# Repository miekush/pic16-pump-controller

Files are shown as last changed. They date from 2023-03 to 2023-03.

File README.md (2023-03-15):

# pic16-pump-controller
PIC16 based Pump Controller for Smart Plant Watering and Coffee Makers

# PCB

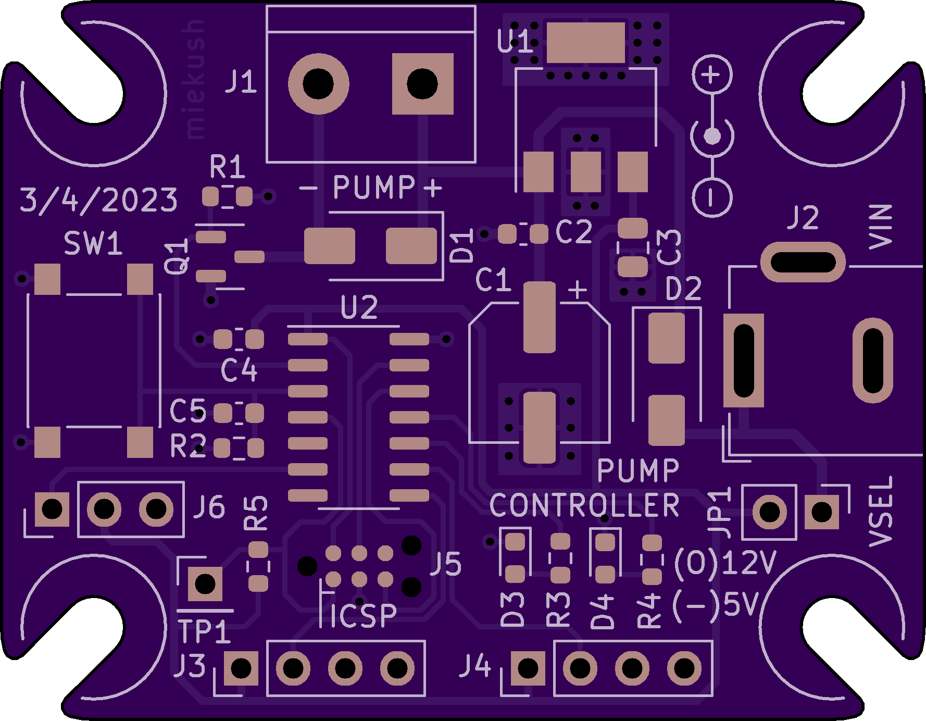
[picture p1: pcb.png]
Board Image


# License

MKE supports the open source hardware community by sharing hardware design files freely on GitHub!

Please support MKE by purchasing products on [Tindie](https://www.tindie.com/stores/mkengineering/)!

Designed by Mike Kushnerik (miekush)

Licensed under [Creative Commons Attribution-ShareAlike CC BY-SA 4.0](http://creativecommons.org/licenses/by-sa/4.0/)

All text above must be included in any redistribution!

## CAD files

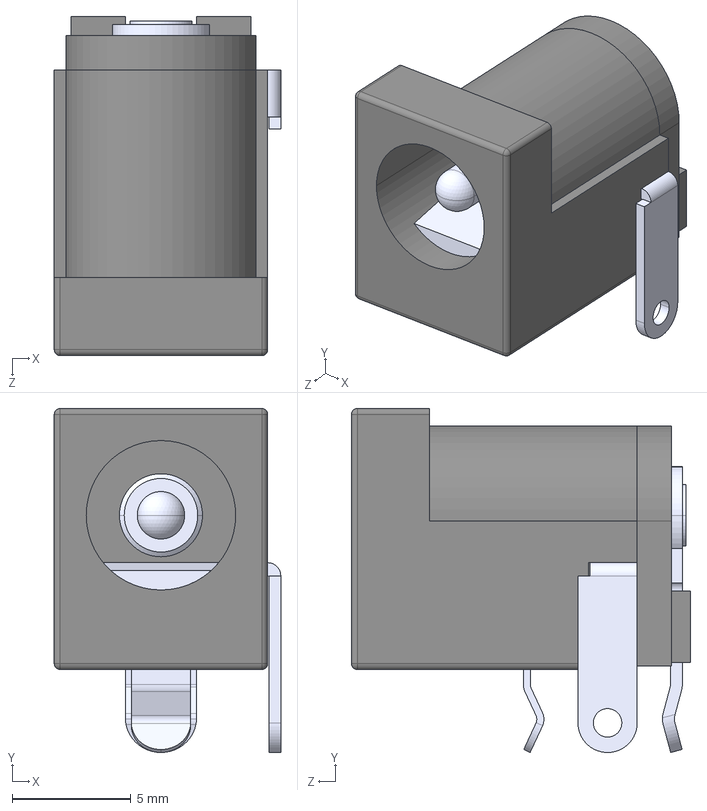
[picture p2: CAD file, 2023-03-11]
DCJ200-10-A-K1-K--3DModel-STEP-56544.STEP
9.55 x 14.5 x 14.3 mm

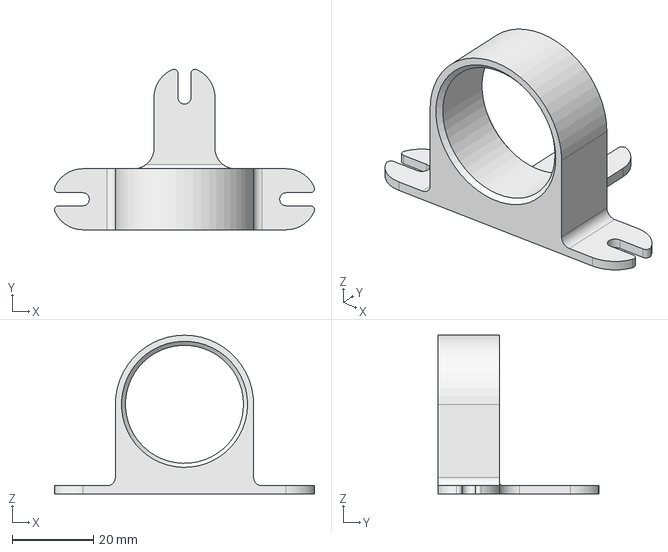
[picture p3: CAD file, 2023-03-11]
pump-suction-mount/pump_suction_mount.FCStd
63.9 x 39.5 x 39.0 mm

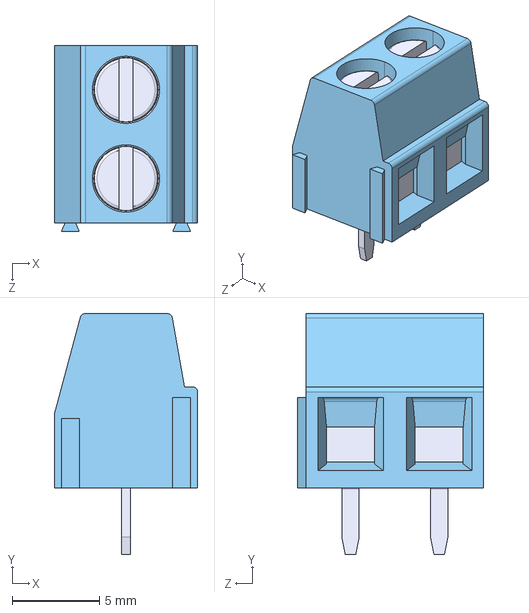
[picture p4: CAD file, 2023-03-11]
CUI_DEVICES_TB006-508-02BE.step
8.20 x 13.8 x 10.7 mm

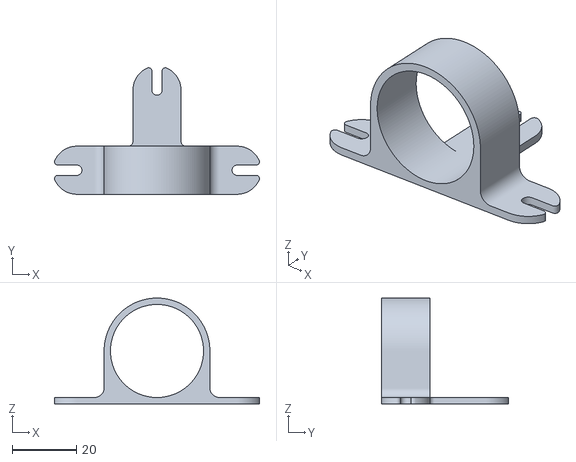
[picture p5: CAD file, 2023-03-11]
pump-suction-mount/pump_suction_mount-Body.stl
63.9 x 39.5 x 33.0

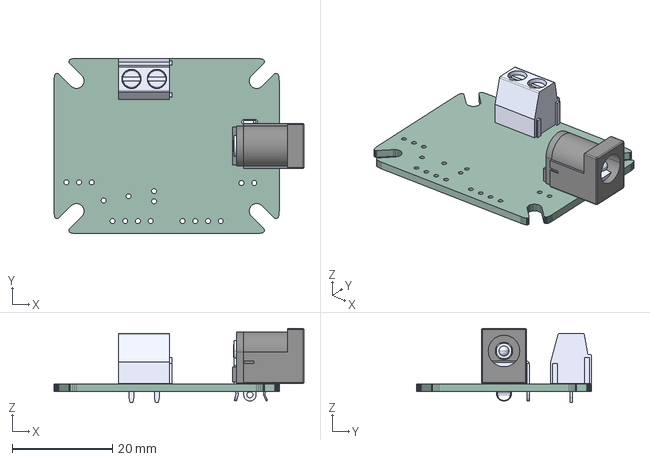
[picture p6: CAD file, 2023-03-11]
pic16-pump-controller.step
49.9 x 35.0 x 14.8 mm
PCB

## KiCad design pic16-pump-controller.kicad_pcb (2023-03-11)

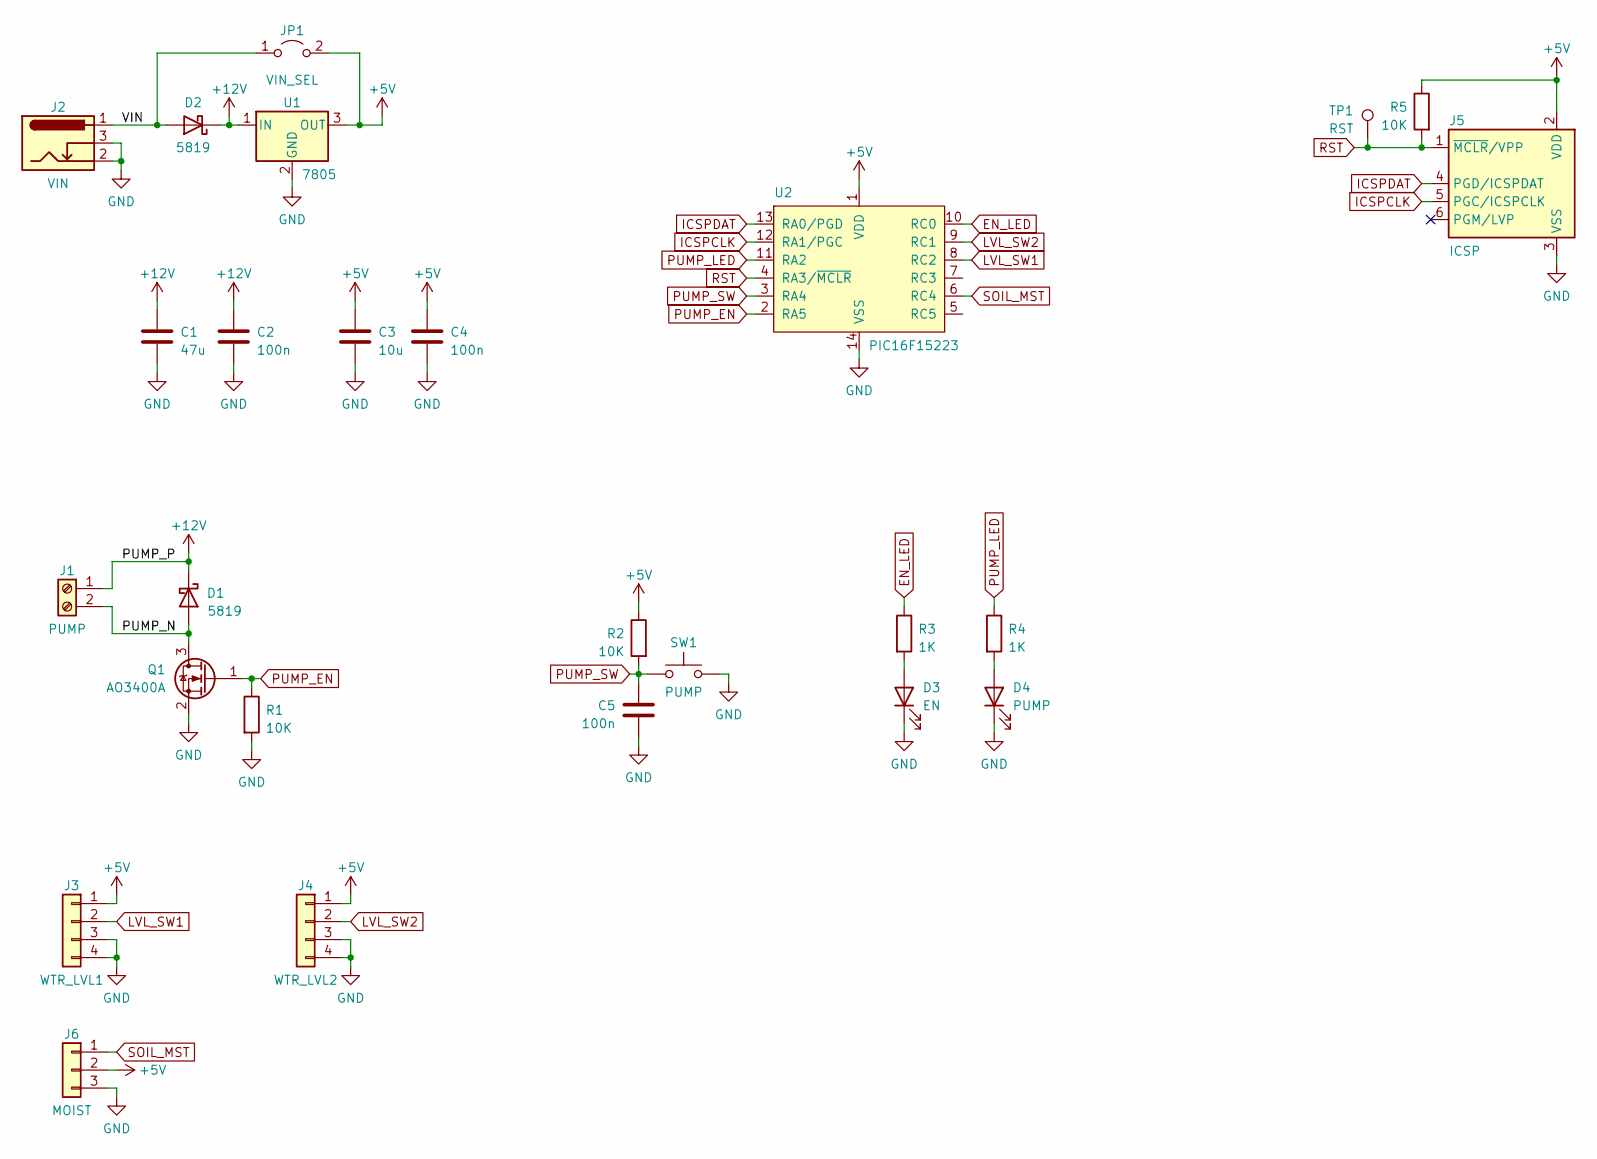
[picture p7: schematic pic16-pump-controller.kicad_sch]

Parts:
C1: 47u; CP_Elec_6.3x5.8
C2, C4, C5: 100n; C_0603_1608Metric
C3: 10u; C_0805_2012Metric
D1, D2: 5819; D_SMA
D3: EN; LED_0603_1608Metric
D4: PUMP; LED_0603_1608Metric
J1: PUMP; TerminalBlock_bornier-2_P5.08mm
J2: VIN; BarrelJack_GCT_DCJ200-10-A_Horizontal
J3: WTR_LVL1; PinHeader_1x04_P2.54mm_Vertical
J4: WTR_LVL2; PinHeader_1x04_P2.54mm_Vertical
J5: ICSP; Tag-Connect_TC2030-IDC-NL_2x03_P1.27mm_Vertical
J6: MOIST; PinHeader_1x03_P2.54mm_Vertical
JP1: VIN_SEL; PinHeader_1x02_P2.54mm_Vertical
Q1: AO3400A; SOT-23
R1, R2, R5: 10K; R_0603_1608Metric
R3, R4: 1K; R_0603_1608Metric
SW1: PUMP; SW_Push_1P1T_NO_6x6mm_H9.5mm
TP1: RST; PinHeader_1x01_P2.54mm_Vertical
U1: 7805; SOT-223-3_TabPin2
U2: PIC16F15223; SOIC-14_3.9x8.7mm_P1.27mm

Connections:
+5V: C3.1, C4.1, J3.1, J4.1, J5.2 (VDD), J6.2, JP1.2 (B), R2.1, R5.1, U1.3 (OUT), U2.1 (VDD)
+12V: C1.1, C2.1, D1.1 (K), D2.1 (K), J1.1, U1.1 (IN)
/PUMP_N: D1.2 (A), J1.2, Q1.3 (D)
/VIN: D2.2 (A), J2.1, JP1.1 (A)
EN_LED: R3.1, U2.10 (RC0)
GND: C1.2, C2.2, C3.2, C4.2, C5.2, D3.1 (K), D4.1 (K), J2.2, J2.3, J3.3, J3.4, J4.3, J4.4, J5.3 (VSS), J6.3, Q1.2 (S), R1.2, SW1.2, U1.2 (GND), U2.14 (VSS)
ICSPCLK: J5.5 (PGC/ICSPCLK), U2.12 (RA1/PGC)
ICSPDAT: J5.4 (PGD/ICSPDAT), U2.13 (RA0/PGD)
LVL_SW1: J3.2, U2.8 (RC2)
LVL_SW2: J4.2, U2.9 (RC1)
unnamed: D3.2 (A), R3.2
unnamed: D4.2 (A), R4.2
PUMP_EN: Q1.1 (G), R1.1, U2.2 (RA5)
PUMP_LED: R4.1, U2.11 (RA2)
PUMP_SW: C5.1, R2.2, SW1.1, U2.3 (RA4)
RST: J5.1 (~MCLR/VPP), R5.2, TP1.1, U2.4 (RA3/~MCLR)
SOIL_MST: J6.1, U2.6 (RC4)

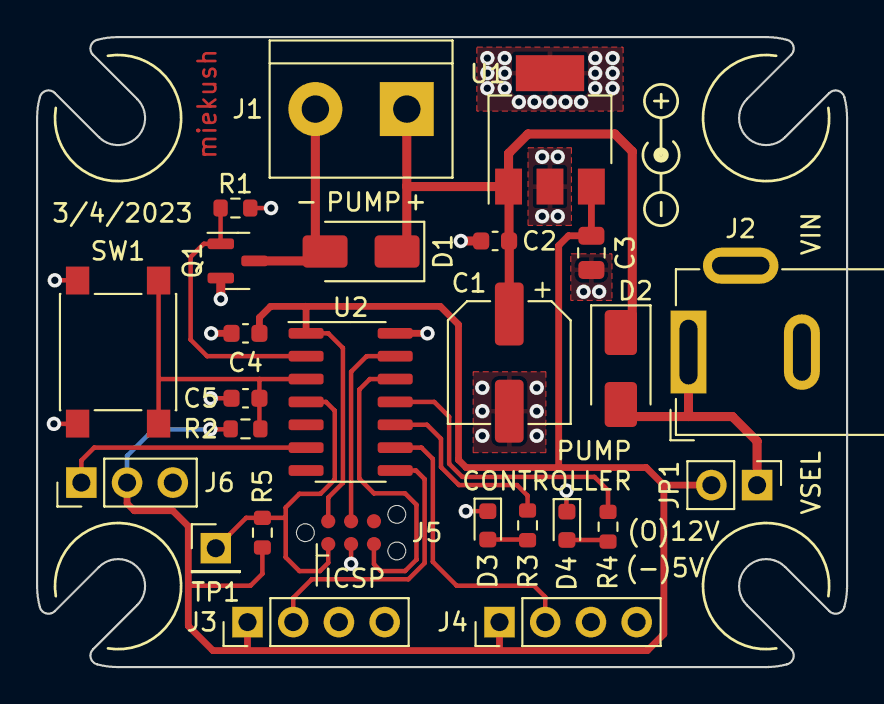
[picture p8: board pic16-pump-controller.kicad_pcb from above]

Board: 2 copper layers, 45.0 x 35.0 mm, 26 parts (0 on the bottom side), 17 nets.

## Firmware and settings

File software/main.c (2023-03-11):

#include "mcc_generated_files/mcc.h"

uint8_t pumpState = false;
uint16_t pumpCounter = 0;
const uint16_t tankFillTime = 5000;

uint16_t ledCounter = 0;
const uint16_t ledPeriod = 500;

//function prototypes
void levelSwISR(void);
void timer0ISR(void);

void main(void)
{
    // initialize the device
    SYSTEM_Initialize();

    // Enable the Global Interrupts
    INTERRUPT_GlobalInterruptEnable();

    // Enable the Peripheral Interrupts
    INTERRUPT_PeripheralInterruptEnable();
    
    //attach interrupt handlers
    TMR0_SetInterruptHandler(timer0ISR);
    IOCCF2_SetInterruptHandler(levelSwISR);

    TMR0_StartTimer();
    
    while (1)
    {
        //pump on
        if((pumpState || !PUMP_SW_GetValue()) && !LVL_SW2_GetValue())
        {
            PUMP_EN_SetHigh();
            PUMP_LED_SetHigh();
            
            if(ledCounter > ledPeriod)
            {
                STAT_LED_Toggle();
                ledCounter = 0;
            }
        }
        //pump off
        else
        {
            PUMP_EN_SetLow();
            PUMP_LED_SetLow();
            
            if(!LVL_SW2_GetValue())
            {
                STAT_LED_SetHigh();
            }
            else
            {
                STAT_LED_SetLow();
            }
        }
    }
}

void levelSwISR(void)
{
    pumpState = true;
    pumpCounter = 0;
    ledCounter = 0;
}

void timer0ISR(void)
{
    pumpCounter++;
    ledCounter++;
    
    if(pumpState && (pumpCounter > tankFillTime))
    {
        pumpState = false;
    }
}

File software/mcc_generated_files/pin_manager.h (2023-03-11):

/**
  @Generated Pin Manager Header File

  @Company:
    Microchip Technology Inc.

  @File Name:
    pin_manager.h

  @Summary:
    This is the Pin Manager file generated using PIC10 / PIC12 / PIC16 / PIC18 MCUs

  @Description
    This header file provides APIs for driver for .
    Generation Information :
        Product Revision  :  PIC10 / PIC12 / PIC16 / PIC18 MCUs - 1.81.8
        Device            :  PIC16F15223
        Driver Version    :  2.11
    The generated drivers are tested against the following:
        Compiler          :  XC8 2.36 and above
        MPLAB 	          :  MPLAB X 6.00	
*/

/*
    (c) 2018 Microchip Technology Inc. and its subsidiaries. 
    
    Subject to your compliance with these terms, you may use Microchip software and any 
    derivatives exclusively with Microchip products. It is your responsibility to comply with third party 
    license terms applicable to your use of third party software (including open source software) that 
    may accompany Microchip software.
    
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
    IN NO EVENT WILL MICROCHIP BE LIABLE FOR ANY INDIRECT, SPECIAL, PUNITIVE, 
    INCIDENTAL OR CONSEQUENTIAL LOSS, DAMAGE, COST OR EXPENSE OF ANY KIND 
    WHATSOEVER RELATED TO THE SOFTWARE, HOWEVER CAUSED, EVEN IF MICROCHIP 
    HAS BEEN ADVISED OF THE POSSIBILITY OR THE DAMAGES ARE FORESEEABLE. TO 
    THE FULLEST EXTENT ALLOWED BY LAW, MICROCHIP'S TOTAL LIABILITY ON ALL 
    CLAIMS IN ANY WAY RELATED TO THIS SOFTWARE WILL NOT EXCEED THE AMOUNT 
    OF FEES, IF ANY, THAT YOU HAVE PAID DIRECTLY TO MICROCHIP FOR THIS 
    SOFTWARE.
*/

#ifndef PIN_MANAGER_H
#define PIN_MANAGER_H

/**
  Section: Included Files
*/

#include <xc.h>

#define INPUT   1
#define OUTPUT  0

#define HIGH    1
#define LOW     0

#define ANALOG      1
#define DIGITAL     0

#define PULL_UP_ENABLED      1
#define PULL_UP_DISABLED     0

// get/set PUMP_LED aliases
#define PUMP_LED_TRIS                 TRISAbits.TRISA2
#define PUMP_LED_LAT                  LATAbits.LATA2
#define PUMP_LED_PORT                 PORTAbits.RA2
#define PUMP_LED_WPU                  WPUAbits.WPUA2
#define PUMP_LED_OD                   ODCONAbits.ODCA2
#define PUMP_LED_ANS                  ANSELAbits.ANSA2
#define PUMP_LED_SetHigh()            do { LATAbits.LATA2 = 1; } while(0)
#define PUMP_LED_SetLow()             do { LATAbits.LATA2 = 0; } while(0)
#define PUMP_LED_Toggle()             do { LATAbits.LATA2 = ~LATAbits.LATA2; } while(0)
#define PUMP_LED_GetValue()           PORTAbits.RA2
#define PUMP_LED_SetDigitalInput()    do { TRISAbits.TRISA2 = 1; } while(0)
#define PUMP_LED_SetDigitalOutput()   do { TRISAbits.TRISA2 = 0; } while(0)
#define PUMP_LED_SetPullup()          do { WPUAbits.WPUA2 = 1; } while(0)
#define PUMP_LED_ResetPullup()        do { WPUAbits.WPUA2 = 0; } while(0)
#define PUMP_LED_SetPushPull()        do { ODCONAbits.ODCA2 = 0; } while(0)
#define PUMP_LED_SetOpenDrain()       do { ODCONAbits.ODCA2 = 1; } while(0)
#define PUMP_LED_SetAnalogMode()      do { ANSELAbits.ANSA2 = 1; } while(0)
#define PUMP_LED_SetDigitalMode()     do { ANSELAbits.ANSA2 = 0; } while(0)

// get/set PUMP_SW aliases
#define PUMP_SW_TRIS                 TRISAbits.TRISA4
#define PUMP_SW_LAT                  LATAbits.LATA4
#define PUMP_SW_PORT                 PORTAbits.RA4
#define PUMP_SW_WPU                  WPUAbits.WPUA4
#define PUMP_SW_OD                   ODCONAbits.ODCA4
#define PUMP_SW_ANS                  ANSELAbits.ANSA4
#define PUMP_SW_SetHigh()            do { LATAbits.LATA4 = 1; } while(0)
#define PUMP_SW_SetLow()             do { LATAbits.LATA4 = 0; } while(0)
#define PUMP_SW_Toggle()             do { LATAbits.LATA4 = ~LATAbits.LATA4; } while(0)
#define PUMP_SW_GetValue()           PORTAbits.RA4
#define PUMP_SW_SetDigitalInput()    do { TRISAbits.TRISA4 = 1; } while(0)
#define PUMP_SW_SetDigitalOutput()   do { TRISAbits.TRISA4 = 0; } while(0)
#define PUMP_SW_SetPullup()          do { WPUAbits.WPUA4 = 1; } while(0)
#define PUMP_SW_ResetPullup()        do { WPUAbits.WPUA4 = 0; } while(0)
#define PUMP_SW_SetPushPull()        do { ODCONAbits.ODCA4 = 0; } while(0)
#define PUMP_SW_SetOpenDrain()       do { ODCONAbits.ODCA4 = 1; } while(0)
#define PUMP_SW_SetAnalogMode()      do { ANSELAbits.ANSA4 = 1; } while(0)
#define PUMP_SW_SetDigitalMode()     do { ANSELAbits.ANSA4 = 0; } while(0)

// get/set PUMP_EN aliases
#define PUMP_EN_TRIS                 TRISAbits.TRISA5
#define PUMP_EN_LAT                  LATAbits.LATA5
#define PUMP_EN_PORT                 PORTAbits.RA5
#define PUMP_EN_WPU                  WPUAbits.WPUA5
#define PUMP_EN_OD                   ODCONAbits.ODCA5
#define PUMP_EN_ANS                  ANSELAbits.ANSA5
#define PUMP_EN_SetHigh()            do { LATAbits.LATA5 = 1; } while(0)
#define PUMP_EN_SetLow()             do { LATAbits.LATA5 = 0; } while(0)
#define PUMP_EN_Toggle()             do { LATAbits.LATA5 = ~LATAbits.LATA5; } while(0)
#define PUMP_EN_GetValue()           PORTAbits.RA5
#define PUMP_EN_SetDigitalInput()    do { TRISAbits.TRISA5 = 1; } while(0)
#define PUMP_EN_SetDigitalOutput()   do { TRISAbits.TRISA5 = 0; } while(0)
#define PUMP_EN_SetPullup()          do { WPUAbits.WPUA5 = 1; } while(0)
#define PUMP_EN_ResetPullup()        do { WPUAbits.WPUA5 = 0; } while(0)
#define PUMP_EN_SetPushPull()        do { ODCONAbits.ODCA5 = 0; } while(0)
#define PUMP_EN_SetOpenDrain()       do { ODCONAbits.ODCA5 = 1; } while(0)
#define PUMP_EN_SetAnalogMode()      do { ANSELAbits.ANSA5 = 1; } while(0)
#define PUMP_EN_SetDigitalMode()     do { ANSELAbits.ANSA5 = 0; } while(0)

// get/set STAT_LED aliases
#define STAT_LED_TRIS                 TRISCbits.TRISC0
#define STAT_LED_LAT                  LATCbits.LATC0
#define STAT_LED_PORT                 PORTCbits.RC0
#define STAT_LED_WPU                  WPUCbits.WPUC0
#define STAT_LED_OD                   ODCONCbits.ODCC0
#define STAT_LED_ANS                  ANSELCbits.ANSC0
#define STAT_LED_SetHigh()            do { LATCbits.LATC0 = 1; } while(0)
#define STAT_LED_SetLow()             do { LATCbits.LATC0 = 0; } while(0)
#define STAT_LED_Toggle()             do { LATCbits.LATC0 = ~LATCbits.LATC0; } while(0)
#define STAT_LED_GetValue()           PORTCbits.RC0
#define STAT_LED_SetDigitalInput()    do { TRISCbits.TRISC0 = 1; } while(0)
#define STAT_LED_SetDigitalOutput()   do { TRISCbits.TRISC0 = 0; } while(0)
#define STAT_LED_SetPullup()          do { WPUCbits.WPUC0 = 1; } while(0)
#define STAT_LED_ResetPullup()        do { WPUCbits.WPUC0 = 0; } while(0)
#define STAT_LED_SetPushPull()        do { ODCONCbits.ODCC0 = 0; } while(0)
#define STAT_LED_SetOpenDrain()       do { ODCONCbits.ODCC0 = 1; } while(0)
#define STAT_LED_SetAnalogMode()      do { ANSELCbits.ANSC0 = 1; } while(0)
#define STAT_LED_SetDigitalMode()     do { ANSELCbits.ANSC0 = 0; } while(0)
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
